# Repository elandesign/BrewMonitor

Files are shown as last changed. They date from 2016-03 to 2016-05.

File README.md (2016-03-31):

# Brew Monitor

An attempt to build a WiFi connected hydrometer & temperature monitor

## Theory

As wort ferments, the specific gravity (i.e. density relative to water) falls. Using Archimedes’ principle we can determine the SG at any given time by suspending a weight of known volume and mass in the fermenting wort.

_The following working assumes a density of 1g/cc of pure water under ideal conditions._

> A weight of volume 100cc and 150g mass is submersed in pure water. The upwards force is equal to the volume of displaced water (100g), giving the weight a net mass of 50g.
> 
> The same weight submersed in wort at 1.050 SG would displace 105g of wort giving the weight a net mass of 45g.
> 
> Measuring the change in force imparted by the weight over time will allow us to accurately monitor the fermentation process.
> 
> Corrections can be applied to account for temperature and atmospheric pressure if needed.

## Design

At its simplest, the brew monitor should consist of a weight attached to a load cell. The weight should be of a known volume and mass (we can ignore the mass and volume of the cord suspending the weight as negligible)

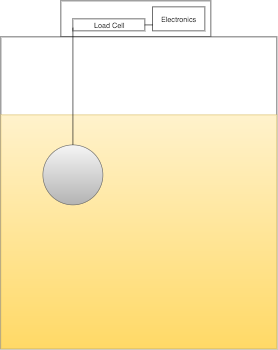
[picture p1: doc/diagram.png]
Simple diagram


The weight must have a greater density than that of the wort in order to sink, so I’ll aim for 1.2g/cc (1.200) which should be more than enough for even the strongest brews.

## Prototype Bill of Materials (all from eBay)

* 6cm plastic sphere
* Stainless steel wire
* 100g Load Cell
* HX711 Load Cell ADC
* ESP-03 ESP8266 Module
* BMP180 Temperature/Pressure Sensor
* 128x64 OLED Display
* 3.3V Regulator
* Reset Switch
* Power Socket
* Circuit Board (Eagle files tbc)
* Enclosure
* PSU

## Software Plan

### Initialization:

* Check reset switch state
  * Holding reset for n seconds when applying power clears filesystem settings
* Load settings from filesystem
  * If wifi settings are present, attempt to connect to wifi
  * If not start in AP mode to allow initial configuration

### Run Mode:

* Accept http GETs to /status.json - return JSON temperature/weight/pressure/sg readings
* Accept http POSTs to /configure - write settings to filesystem
* Accept http GETs to /settings - read current config from filesystem
* Periodically send JSON status to external server if configured
* Tare - press reset switch for n seconds to update tare reading in filesystem settings

### OTA Updates:

* It should be possible to update the firmware over the internet

## Unknowns & Problem Areas

* We need to accurately measure the volume of the weight
* Do we need to calibrate the load cell?
* How can we account for CO2 bubbles adhering to the surface of the weight? Will the effect be significant?
* Does the density of wort due to temperature and pressure change in line with that of pure water?
* Ideally we’d take the temperature of the wort - will ambient temperature be good enough to get reasonable accuracy?
* How do we enclose the thing? An off the shelf project box would be best to keep price down, but we need to be careful not to expose the wort to infection - would need to be airtight. Also, if this is to replace the airlock we’d need a bubbler/blowoff tube as part of the setup.
* Is the weight food-safe?

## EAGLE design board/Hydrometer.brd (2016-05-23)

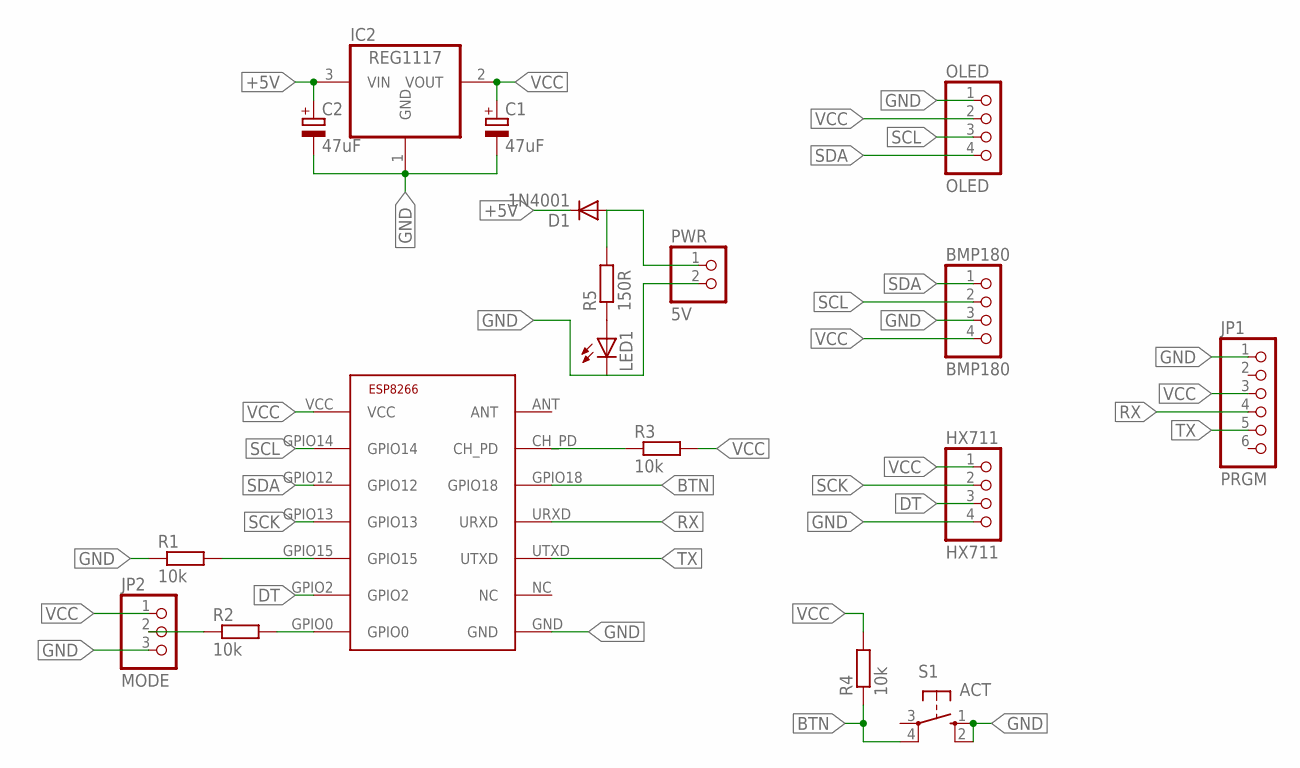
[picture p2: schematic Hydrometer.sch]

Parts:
BMP180: BMP180; 1X04
C1: 47uF; E2-5
C2: 47uF; E2,5-5
D1: 1N4001; DO41-10
HX711: HX711; 1X04
IC2: REG1117; SOT223
JP1: PRGM; 1X06
JP2: MODE; 1X03
LED1: LED3MM
OLED: OLED; 1X04
PWR: 5V; 1X02
R1, R3, R4: 10k; R1206
R2: 10k; 0204/7
R5: 150R; 0204/7
S1: ACT; B3F-10XX
U$1: ESP8266-03; ESP-03

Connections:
+5V: C2.+, D1.C, IC2.3 (VIN)
BTN: R4.1, S1.4 (P1), U$1.GPIO18
DT: HX711.3, U$1.GPIO2
DTR: R2.2, U$1.GPIO0
GND: BMP180.3, C1.-, C2.-, HX711.4, IC2.1 (GND), JP1.1, JP2.3, LED1.K (C), OLED.1, PWR.2, R1.1, S1.1 (S), S1.2 (S1), U$1.GND
unnamed: JP2.2, R2.1
unnamed: R1.2, U$1.GPIO15
unnamed: D1.A, PWR.1, R5.2
unnamed: R3.1, U$1.CH_PD
unnamed: LED1.A, R5.1
RX: JP1.4, U$1.URXD
SCK: HX711.2, U$1.GPIO13
SCL: BMP180.2, OLED.3, U$1.GPIO14
SDA: BMP180.1, OLED.4, U$1.GPIO12
TX: JP1.5, U$1.UTXD
VCC: BMP180.4, C1.+, HX711.1, IC2.2 (VOUT), JP1.3, JP2.1, OLED.2, R3.2, R4.2, U$1.VCC

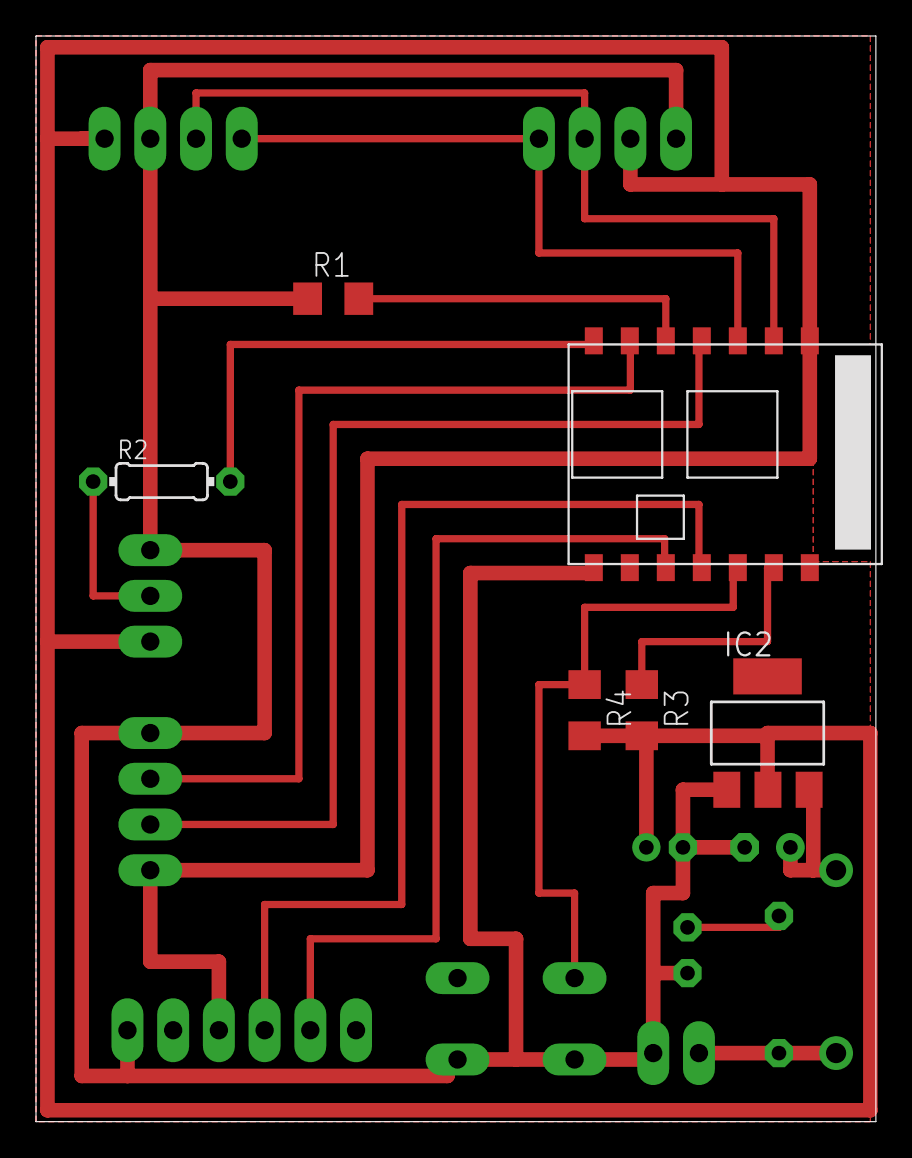
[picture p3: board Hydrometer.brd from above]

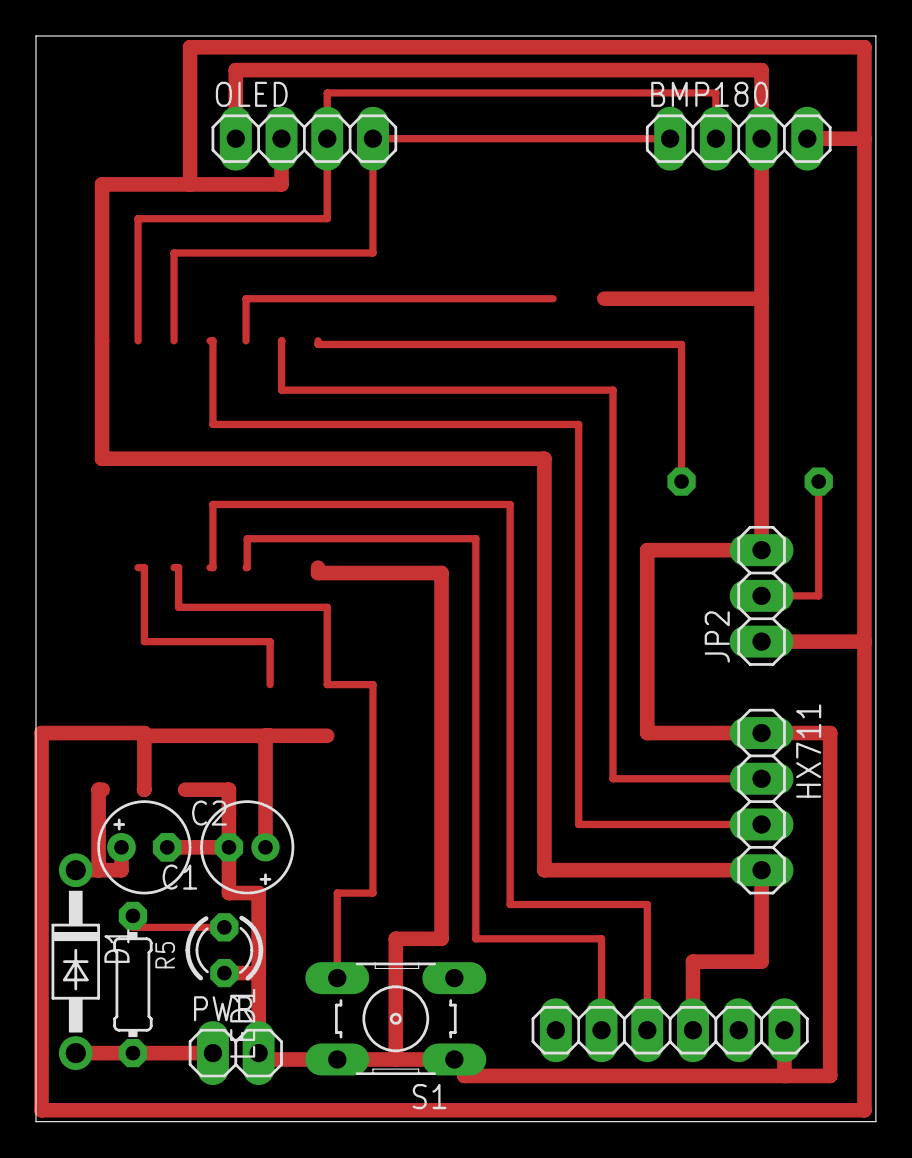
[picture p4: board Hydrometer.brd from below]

Board: 2 copper layers, 46.7 x 60.3 mm, 18 parts (12 on the bottom side), 16 nets.

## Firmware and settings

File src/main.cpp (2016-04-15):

#include "Arduino.h"
#include <Ticker.h>

#include "globals.h"
#include "config.h"
#include "button.h"
#include "display.h"
#include "wifi.h"
#include "web_server.h"
#include "mdns.h"
#include "sensors.h"
#include "graphite.h"

Ticker ticker;

bool takeReadingsNow = false;

void tick() {
  takeReadingsNow = true;
}

void setup() {

  delay(5000);
  Serial.begin(115200);

  buttonSetup();

  configSetup();

  if(wifiAP)
    wifiSetupAP();
  else {
    wifiSetup();
    mdnsSetup();
  }

  sensorsSetup();

  ticker.attach(takeReadingsEvery, tick);

  webServerSetup();
}

void loop() {
  buttonLoop();
  webServerLoop();

  if(takeReadingsNow) {
    takeReadingsNow = false;
    sensorsRead();
    if(graphiteServer)
      sendReadingsToGraphite();
  }
}

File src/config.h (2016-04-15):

#include <ArduinoJson.h>
#include "FS.h"
#include "globals.h"

#ifndef CONFIG_H
#define CONFIG_H

#define CONFIGURATION "/config.json"
#define CONFIGURATION_WIFI_AP "wifiAP"
#define CONFIGURATION_WIFI_SSID "wifiSSID"
#define CONFIGURATION_WIFI_PASSWORD "wifiPassword"
#define CONFIGURATION_SERVER_NAME "serverName"
#define CONFIGURATION_ADMIN_PASSWORD "adminPassword"

#define CONFIGURATION_GRAPHITE_SERVER "graphiteServer"
#define CONFIGURATION_GRAPHITE_PORT "graphitePort"
#define CONFIGURATION_GRAPHITE_METRIC "graphiteMetric"

void configSetup();
bool configLoad();
void configReset();

#endif

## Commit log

2016-03-31 Add eagle schematic
    [Hydrometer.brd, Hydrometer.sch]
2016-04-05 Clean up schematic and board
    [Hydrometer.brd, Hydrometer.sch]
2016-04-15 Read the load cell along with other sensors
2016-04-23 Switch from Makefile to platformio builds
2016-05-22 Update board layout to a (mostly) single sided PCB
    [Hydrometer.brd, Hydrometer.sch]
2016-05-22 Switch from Makefile to PlatformIO build system
2016-05-22 Remove unused SPI code from SSD1306 library
2016-05-22 Add fill planes to board
    [Hydrometer.brd, Hydrometer.sch]
2016-05-23 Add input protection and power LED
    [Hydrometer.brd, Hydrometer.sch]
